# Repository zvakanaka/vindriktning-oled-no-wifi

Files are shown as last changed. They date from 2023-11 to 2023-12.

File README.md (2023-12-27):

> This is a derivative of https://github.com/Hypfer/esp8266-vindriktning-particle-sensor with the following changes:
- OLED display (128x64 I2C)
- Temperature & humidity sensor (DHT22 on GPIO14 - D5)
- Particle sensor Rx moved from GPIO4 (D2) -> GPIO12 (D6)
- No WiFi

<p align="center"><h2>OLED Display and Temperature/Humidity for the Ikea VINDRIKTNING</h2></p>

This repository contains an ESP8266 firmware, which adds a display as well as a temperature/humidity sensor to the Ikea VINDRIKTNING PM2.5 air quality sensor.
The modification  doesn't interfere with normal operation of the device in any way.
The ESP8266 just adds another data sink beside the colored LEDs.

As the ESP8266 is 5V-tolerant, this should there shouldn't be any issues, however I haven't had time to test this for longer periods of time.
Therefore, if the ESP burns out after a while, just add a voltage divider or something.

## Videos

https://github.com/zvakanaka/vindriktning-oled-no-wifi/assets/8365885/152a4b98-3d9d-4007-931a-cf2efa4b7743

https://github.com/zvakanaka/vindriktning-oled-no-wifi/assets/8365885/816829d6-6ecd-432c-b0bc-8723ba30da9b

## Prerequisites

To extend your air quality sensor, you will need

- An ESP8266 with a 5v voltage regulator (e.g. a Wemos D1 Mini)
- Some short dupont cables
- A soldering iron
- A long PH0 Screwdriver (e.g. Wera 118022)

Fortunately, there is a lot of unused space in the enclosure, which is perfect for our ESP8266.
Also, everything we need is accessible via easy to solder testpoints.

## Hardware

To install the ESP8266, you need to unscrew the four visible screws in the back of the enclosure.

Then, there are also three screws holding the tiny PCB in place. These aren't necessary to remove since you can solder
in-place, however personally, I'd recommend taking the board out of there since it will be easier to solder without fear
of accidentally melting some plastic.

As you can see in this image, you'll need to solder wires to GND, 5V and the Testpoint that is connected to TX of the
Particle Sensor.

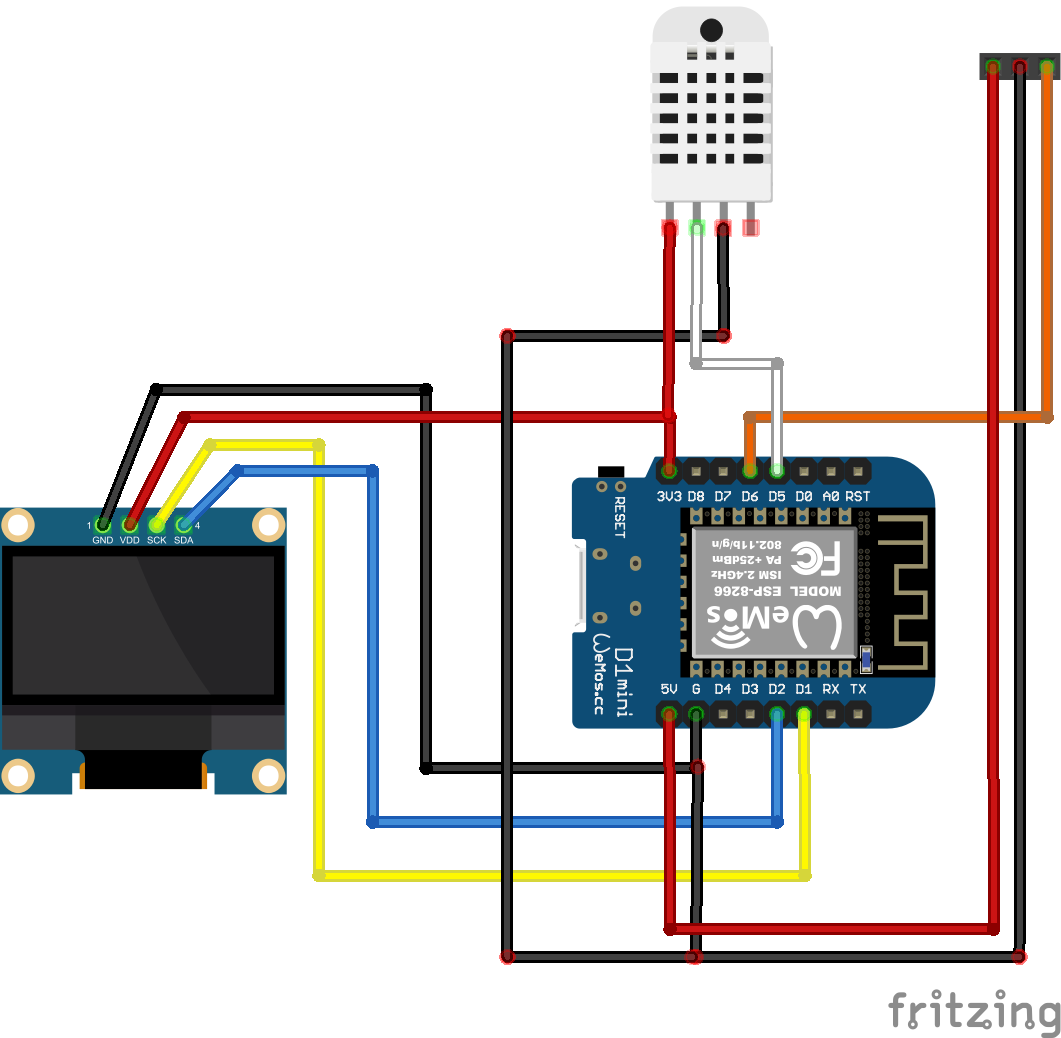
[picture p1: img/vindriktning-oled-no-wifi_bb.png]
wiring-diagram


### Particle Sensor
For the particle sensor, just connect these Wires to GND, VIN (5V) and ~~D2~~ D6, which is GPIO12 (if you're using a Wemos D1 Mini).

### OLED Screen (128x64 I2C)
SCL -> D1 (GPIO5) and SDA -> D2 (GPIO4).

### Temperature/Humidity Sensor (DHT22)
Data -> D5 (GPIO14).

Done.

## Software

The firmware can be built and flashed using the Arduino IDE, but PlatformIO would be much easier because it will automatically pull in the libraries for you.

For Arduino IDE, you will need to rename the `*.cpp` file in `src/` to end in `.ino` instead of `.cpp` and add ESP8266 support to Arduino IDE by [using the Boards Manager](https://github.com/esp8266/Arduino#installing-with-boards-manager).

Furthermore, you will also need to install the following libraries using the Library Manager:

- olikraus/U8g2@^2.35.7
- adafruit/DHT sensor library@^1.4.6

Just build, flash, and you're done.

If you'd like to compile and upload this without a UI:  
`platformio run --target upload --upload-port /dev/ttyUSB0`

## Misc

To make soldering a bit easier, note that the whole outer metal part of the Micro USB connector of the D1 Mini is
connected to GND.

The Vindriktning consists of a custom(?) Cubic PM1006-like Sensor + another uC that does all that LED stuff, which talk
via UART. The uC simply regularly polls the sensor and displays the results.

As reported in #16, the transitions from Green to Yellow and Yellow to Red in the Ikea firmware are at around 30 and 100μg/m³.

## References and sources
- [Hypfer's Code](https://github.com/Hypfer/esp8266-vindriktning-particle-sensor)
- [@haxfleisch](https://twitter.com/haxfleisch) for their teardown of the device.
- [Gabriel Valky](https://github.com/gabonator) for the incredibly useful [LA104 custom firmware + tools](https://github.com/gabonator/LA104)

### 3D Models
- [Custom Back](https://www.thingiverse.com/thing:6403319)
- [OLED Frame](https://www.thingiverse.com/thing:2157801) (slides into case)
- [DHT22 Temperature/humidity Sensor Case](https://www.thingiverse.com/thing:1520129) (screws into back using one of the 4 frame-screws through the hole in the white part of the DHT22)

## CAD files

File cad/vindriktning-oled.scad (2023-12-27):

FN=16;

sphereR = 1;
rcWidth = 52;
rCDepth = 46;
rcHeight = 85;
floorThickness = 2;

oledWidth = 33.6979;
oledYOffset = 0.15;
module oled() {
  // size: 33.6979 x 31.8 x 5.2 mm (measured in https://0x00019913.github.io/meshy/)
  rotate([90,0,0])
    // Center an object in the middle of a parent https://stackoverflow.com/a/71715693/4151489
    translate([(rcWidth - oledWidth) / 2,(rCDepth - 31.8),5.25 - rcHeight])
      import("./oled.stl");

}
extraSinkage = 12;
module oledCutout() {
  rotate([90,0,0])
    translate([(rcWidth - (oledWidth + .5)) / 2,(rCDepth - 31.8 - extraSinkage),-rcHeight - .01])
      cube([oledWidth + .5,31.8 + extraSinkage + .01,3]);
}
module oledFrameRails() {
  railWidth = 2;
  railDepth = 1;
  railHeight = 31.9 + extraSinkage;
  module oledFrameRail(xOffset) {
    color("red")
      translate([0,0,-extraSinkage])
        cube([railWidth, railDepth, railHeight - 0.1]);
    color("blue")
      translate([-xOffset,-abs(xOffset) + .01,-extraSinkage])
      cube([railWidth, railDepth , railHeight - 4 ]);
    color("green")
      translate([-(xOffset > 0 ? xOffset : 0), -abs(xOffset) - .75 + .01, -extraSinkage])
        cube([railWidth + abs(xOffset), railDepth, railHeight - 4]);
  }
  // left group of rails
  translate([(rcWidth - (oledWidth + .5)) / 2 - .1, rcHeight - 1, rCDepth - 31.8])
    oledFrameRail(2);
  // right group of rails
  translate([rcWidth - (rcWidth - (oledWidth + .5)) / 2 + .1 - railWidth, rcHeight - 1, rCDepth - 31.8])
    oledFrameRail(-2);
}
//oled();

module floorWallsAndScrewPosts() {
  $fn=FN;
  walls();
  module floor() {
    radius = 2;
    translate([1 + radius,1 + radius,0])
      difference() {
        minkowski() {
          cube([rcWidth - 2 - radius * 2, rcHeight - 2 - radius * 2, floorThickness]);
          sphere(r = radius);
        }
        translate([-radius,-radius,-floorThickness])
          cube([rcWidth + radius,rcHeight + radius,floorThickness]);
        translate([-radius,-radius,floorThickness  ])
          cube([rcWidth + radius,rcHeight + radius,floorThickness]);
      }
  }

  // screw post
  module screwPostOuters(screwPostR = 3, screwPostDistance = 8) {
    translate([screwPostDistance,screwPostDistance,2])
      cylinder(h = 21, r = screwPostR);

    translate([rcWidth - screwPostDistance,screwPostDistance,2])
      cylinder(h = 21, r = screwPostR);

    translate([screwPostDistance,rcHeight - screwPostDistance,2])
        cylinder(h = 21, r = screwPostR);

    translate([rcWidth - screwPostDistance,rcHeight - screwPostDistance,2])
        cylinder(h = 21, r = screwPostR);
  }
  module screwPostInners(screwPostInnerR = 3,  screwPostDistance = 8) {
    screwPostZ = -0.1;
    screwPostHoleR = 1;
    screwPostHoleHeight = 20;
    screwPostInnerHoleHeight = screwPostHoleHeight + 4;
    module screwPostInner1() {
      translate([screwPostDistance,screwPostDistance,screwPostZ])
        cylinder(h = screwPostHoleHeight, r = screwPostInnerR);
      translate([screwPostDistance,screwPostDistance,screwPostZ])
        cylinder(h = screwPostInnerHoleHeight, r = screwPostHoleR);
    }
    module screwPostInner2() {
      translate([rcWidth - screwPostDistance,screwPostDistance,screwPostZ])
        cylinder(h = screwPostHoleHeight, r = screwPostInnerR);
      translate([rcWidth - screwPostDistance,screwPostDistance,screwPostZ])
          cylinder(h = screwPostInnerHoleHeight, r = screwPostHoleR);
    }
    module screwPostInner3() {
      translate([screwPostDistance,rcHeight - screwPostDistance,screwPostZ])
          cylinder(h = screwPostHoleHeight, r = screwPostInnerR);
      translate([screwPostDistance,rcHeight - screwPostDistance,screwPostZ])
          cylinder(h = screwPostInnerHoleHeight, r = screwPostHoleR);
    }
    module screwPostInner4() {
      translate([rcWidth - screwPostDistance,rcHeight - screwPostDistance,screwPostZ])
          cylinder(h = screwPostHoleHeight, r = screwPostInnerR);
      translate([rcWidth - screwPostDistance,rcHeight - screwPostDistance,screwPostZ])
          cylinder(h = screwPostInnerHoleHeight, r = screwPostHoleR);
    }
    // cups at top of screw posts
    cupR = 2.5;
    cupH = 1.1;
    union() {
      screwPostInner1();
      translate([screwPostDistance,screwPostDistance,screwPostInnerHoleHeight-2]) 
        cylinder(h = cupH, r = cupR);
    }
    union() {
      screwPostInner2();
      translate([rcWidth - screwPostDistance,screwPostDistance,screwPostInnerHoleHeight-2]) 
        cylinder(h = cupH, r = cupR);
    }
    union() {
      screwPostInner3();
      translate([screwPostDistance,rcHeight - screwPostDistance,screwPostInnerHoleHeight-2]) 
        cylinder(h = cupH, r = cupR);
    }
    union() {
      screwPostInner4();
      translate([rcWidth - screwPostDistance,rcHeight - screwPostDistance,screwPostInnerHoleHeight-2]) 
        cylinder(h = cupH, r = cupR);
    }
  }
  screwPostR = 3.5;
  screwPostDistance = screwPostR + 3.6;
  screwPostInnerR = 3;
  module floorAndScrewPosts() {
    screwPostOuters(screwPostR, screwPostDistance);
    floor();
  }
  module bottom() {
    difference() {
      floorAndScrewPosts();
      screwPostInners(screwPostInnerR, screwPostDistance);
    }
  }
  bottom();
  // the two posts by the oled frame
  module upperPostSecures() {
    translate([2-.001,rcHeight-9,floorThickness - .001])
      cube([2.5,4,20]);
    translate([rcWidth - 4.5 - .001,rcHeight-9,floorThickness - .001])
      cube([2.5,4,20]);
  }
  upperPostSecures();
  powerCutout();
}

module holes() {
  $fn=FN;
  // holes in floor
  // [start:increment:stop]
  for (i = [80:-4:12]) {
    for (j = [48:-4:4]) {
      if (!(i > 7 * 4 && i < 13 * 4)) {
        // the if is so we don't render the additional hole at the end of the shifted rows
        if (!(i % 8 == 0 && j == 4)
          && !(i == 76 && j == 48)
          && !(i == 76 && j == 44)
          && !(i == 80 && j == 48)
          && !(i == 80 && j == 44)
          && !(i == 76 && j == 4)
          && !(i == 76 && j == 8)
          && !(i == 80 && j == 4)
          && !(i == 80 && j == 8)
          && !(i == 80 && j == 12)
          ) {
          // the ternary is to offset every other row
          translate([(i % 8 == 0) ? j - 2 : j, i,-5])
            cylinder(h = 7.1, r = 1);
        }
      }
    }
  }
}

module innerPowerCutout() {
  $fn=FN;
  minkowski() {
  translate([rcWidth / 2 - 30 / 2 + 1 , -3.001, -1.001])
    cube([28, 10, 26 + 3 + 2]);
    sphere(2);
  }
}

module powerCutout() {
  difference() {
    minkowski() {
    translate([rcWidth / 2 - 30 / 2, 0 - 1.001, 0 - .001])
      cube([30, 10, 27 + 3 + 2]);
      sphere(2);
    }
    innerPowerCutout();
  }
}
module powerCutoutEdges() {
  color("red")
  translate([rcWidth / 2 - 36 / 2, -3, -2]) 
    cube([36, 3, 36]);
  color("blue")
  translate([rcWidth / 2 - 36 / 2, -1, -3]) 
    cube([36, 12.001, 3]);
}

module upperRails() {
  $fn=FN;
  railStartY = 50;
  translate([2,railStartY,2])
    cube([rcWidth - 4, 1, 10]);
  translate([2,railStartY,2])
    cube([3, 1, 24]);
  translate([rcWidth-5,railStartY,2])
    cube([3, 1, 24]);
}
module lowerRails() {
  $fn=FN;
  railStartY = 28;
  translate([2,railStartY,2])
    cube([rcWidth - 4, 1, 3]);
  translate([2,railStartY,2])
    cube([3, 1, 24]);
  translate([rcWidth-5,railStartY,2])
    cube([3, 1, 24]);
}

module usbCPort() {
  translate([(rcWidth - 6) / 2,3.5 + 0.25,25 + 1.75 + 3])
  minkowski() {
    $fn=30;
    cube([6,.001,5]);
    sphere(r = 1.5);
  }
}
module usbPortSupportBlock() {
  s = 1.04;
  color("red")
  difference() {
    translate([(rcWidth - 12) / 2, 4.7, 25 + 1.9 + 3 + 2 + 0.1])
      cube([12,4,4.5]);
    translate([-1.025,.01,-1 + 2])
    scale([s,s,s])
      usbCPort();
  }
}
module usbPortSupportSlider(xOffset) {
  translate([(rcWidth - xOffset) / 2, 1.25, 25 + 1.9 + 3 + 2 + 0.1])
    cube([1,1,8.5]);
}
module usbPortSupportSliders() {
  usbPortSupportSlider(6);
  usbPortSupportSlider(-4);
}

module minkowskiWallsOuter(offset = 0, radius = 5) {
  $fn=45;
  difference() {
    translate([radius + offset / 2,radius + offset / 2,offset / 2])
      minkowski() {
        cube([rcWidth - radius * 2 - offset,rcHeight - radius * 2 - offset,rCDepth]);
        sphere(r = radius);
      }
    if (offset == 0) {
      translate([0,0,-rCDepth + offset / 2])
        cube([rcWidth,rcHeight,rCDepth]);
      translate([0,0,rCDepth - offset / 2])
        cube([rcWidth,rcHeight,rCDepth]);
    } 
  }
}
module walls() {
  difference() {
    minkowskiWallsOuter(0, 5);
    minkowskiWallsOuter(4, 3);
  }
}

module vindriktning() {
  upperRails();
  lowerRails();
  usbPortSupportBlock();
  usbPortSupportSliders();
  difference() {
    floorWallsAndScrewPosts();
    innerPowerCutout();
    powerCutoutEdges();
    usbCPort();
    if (!$preview) {
      holes();
    }
    oledCutout();
  }
  oledFrameRails();
}

vindriktning();
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

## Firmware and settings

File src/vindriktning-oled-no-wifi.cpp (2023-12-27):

#include <Adafruit_Sensor.h>
#include <DHT.h>
#include <U8g2lib.h>
#include <CircularBuffer.h>

#include "SerialCom.h"
#include "Types.h"

U8G2_SH1106_128X64_NONAME_F_HW_I2C u8g2(U8G2_R0);

particleSensorState_t state;

#define statusCheckInterval 3000
#define BOOT_DELAY 3000
#define PARTICLE_SENSOR_LOADING_DELAY 20000

uint32_t statusCheckPreviousMillis = millis();

CircularBuffer<char,126> circBuf; // uses 538 bytes

#define DHTPIN 14     // digital pin connected to the DHT sensor
#define DHTTYPE DHT22 // DHT 22 (AM2302)
DHT dht(DHTPIN, DHTTYPE);

// Yes, this is hacky but it is working in time to make it a Christmas gift!
char identifier[24];
char avgPM25[24];
char fahrenheit[24];
char humidity[24];
#define FIRMWARE_PREFIX "esp8266-vindriktning-particle-sensor-oled"

void setup() {
  Serial.begin(115200);
  SerialCom::setup();
  dht.begin();

  Serial.println("\n");
  Serial.println("Hello from esp8266-vindriktning-particle-sensor");
  Serial.printf("Core Version: %s\n", ESP.getCoreVersion().c_str());
  Serial.printf("Boot Version: %u\n", ESP.getBootVersion());
  Serial.printf("Boot Mode: %u\n", ESP.getBootMode());
  Serial.printf("CPU Frequency: %u MHz\n", ESP.getCpuFreqMHz());
  Serial.printf("Reset reason: %s\n", ESP.getResetReason().c_str());

  u8g2.begin();
  u8g2.setContrast(0);
  u8g2.setFont(u8g2_font_unifont_t_symbols);
  u8g2.drawGlyph((128 - 12) / 2, 40, 0x23f3);
  u8g2.setFont(u8g2_font_simple1_te);
  u8g2.sendBuffer();

  delay(BOOT_DELAY);

  snprintf(identifier, sizeof(identifier), "VINDRIKTNING-%X", ESP.getChipId());
  u8g2_uint_t w = u8g2.getStrWidth(identifier);

  u8g2.setFont(u8g2_font_fub49_tn);
  Serial.printf("%s/%s/status\n", FIRMWARE_PREFIX, identifier);

  Serial.println("-- Current GPIO Configuration --");
  Serial.printf("PIN_UART_RX: %d\n", SerialCom::PIN_UART_RX);
}

void loop() {
  SerialCom::handleUart(state);

  const uint32_t currentMillis = millis();
  if (currentMillis - statusCheckPreviousMillis >= statusCheckInterval) {
    statusCheckPreviousMillis = currentMillis;

    // read temperature and humidity
    float t = dht.readTemperature();
    float h = dht.readHumidity();
    u8g2.clearBuffer();
    bool tempHumError =
        isnan(h) || isnan(t) || h > 100 || h < 0 || t > 100 || t < -40;

    if (tempHumError) {
      // https://github.com/olikraus/u8g2/wiki/fntgrpx11#6x12
      u8g2.setFont(u8g2_font_6x12_tf);

      u8g2.drawStr(0, 64, "Temp/humidity sensor error!");
    } else {
      u8g2.setFont(u8g2_font_9x15_tf);
      snprintf(fahrenheit, sizeof(fahrenheit), "%d F", int((t * 9 / 5) + 32));

      snprintf(humidity, sizeof(humidity), "%d%%", int(h));
      u8g2.drawStr(128 - u8g2.getStrWidth(fahrenheit) - 8, 8 + 3, fahrenheit);
      // degree https://github.com/olikraus/u8g2/wiki/u8g2reference#drawcircle
      u8g2.drawCircle(128 - u8g2.getStrWidth(fahrenheit) * 0.333 - 8 - 1, 2, 1, U8G2_DRAW_ALL);
      u8g2.drawStr(0, 8 + 3, humidity);
    }

    if (state.valid) {
      u8g2.setFont(u8g2_font_fub49_tn);
      snprintf(avgPM25, sizeof(avgPM25), "%d", state.avgPM25);
      u8g2_uint_t w = u8g2.getStrWidth(avgPM25);
      int digitHeight = 62;
      u8g2.drawStr((128 - w) / 2, (64 - digitHeight) / 2 + digitHeight, avgPM25);

      circBuf.push(state.avgPM25);
    } else if (currentMillis < PARTICLE_SENSOR_LOADING_DELAY) {
      u8g2.setFont(u8g2_font_6x12_tr);
      u8g2.drawStr(0, 38, "Air sensor loading");
    } else {
      u8g2.setFont(u8g2_font_6x12_tr);
      u8g2.drawStr(0, 38, "Air sensor error");
    }

    for (decltype(circBuf)::index_t i = 0; i < circBuf.size(); i++) {
      if (i != 0) {
        u8g2.drawLine(i,     63 - circBuf[i],
                      i - 1, 63 - circBuf[i - 1]);
      }
    }

    u8g2.sendBuffer();
  }
}

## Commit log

2023-11-25 1st ☄️
2023-11-30 detect/handle errors better and temp/hum is optional
    [vindriktning-oled-no-wifi.cpp]
2023-12-20 bigger font size, wait for air sensor before erroring, schematic
    [vindriktning-oled-no-wifi.fzz]
2023-12-27 add OpenSCAD
    [vindriktning-oled-no-wifi.fzz, vindriktning-oled.scad]
